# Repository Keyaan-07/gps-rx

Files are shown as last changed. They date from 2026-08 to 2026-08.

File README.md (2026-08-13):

# GPS Receiver
GPS-RX is a custom-hardware, low-power GPS receiver that is just 16x16mm in size. This receiver does not have any COCOM limits and is fully customisable. It uses UART to communicate with other external controllers and takes a 3.3 volt input. Unlike other GPS receivers, there are no speed or height based limits and can go to any height or any speeds. It is built like a really small module and can be built and assembled by anyone and used basically everywhere. I built this project to learn verilog and also because this seems really cool! The ice40up5k from lattice semiconductor is the FPGA that processes the GPS signals. 

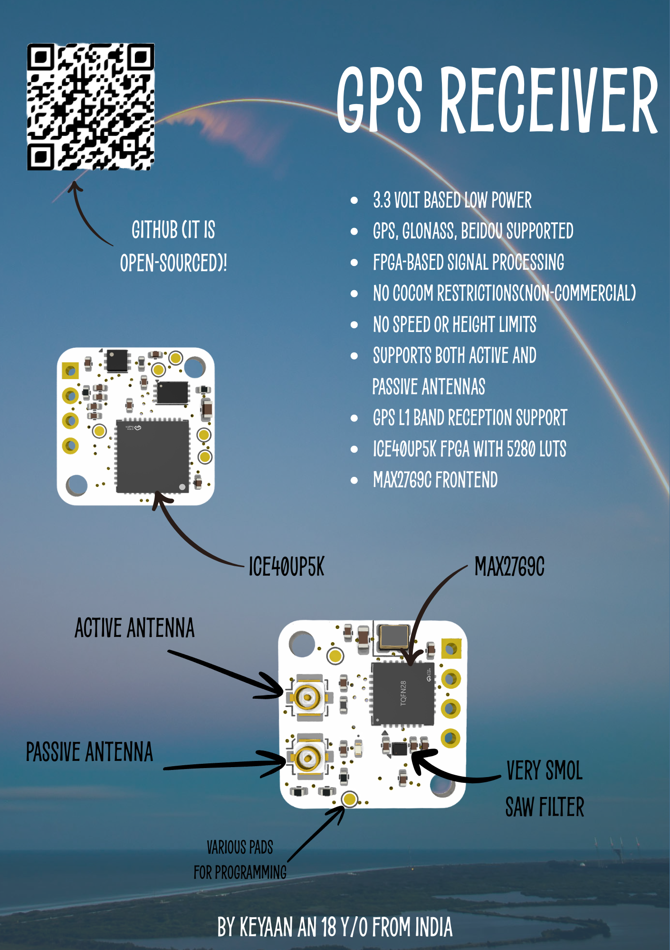
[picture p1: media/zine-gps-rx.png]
zine

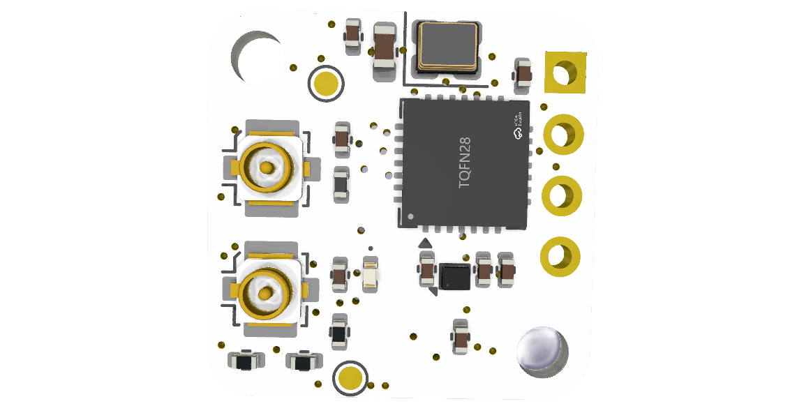
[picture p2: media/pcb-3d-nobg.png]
3d pcb

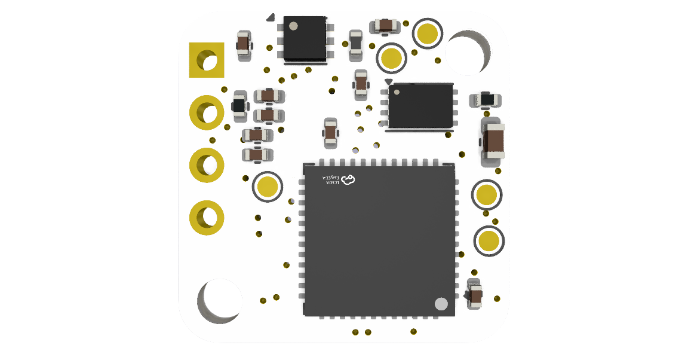
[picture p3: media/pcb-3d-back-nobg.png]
3d pcb back

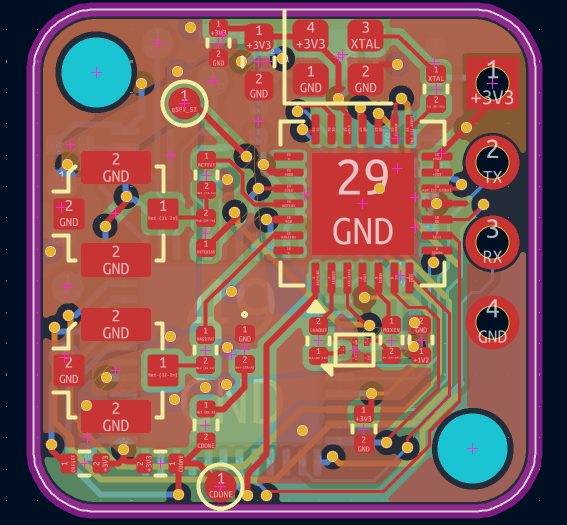
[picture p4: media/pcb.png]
pcb

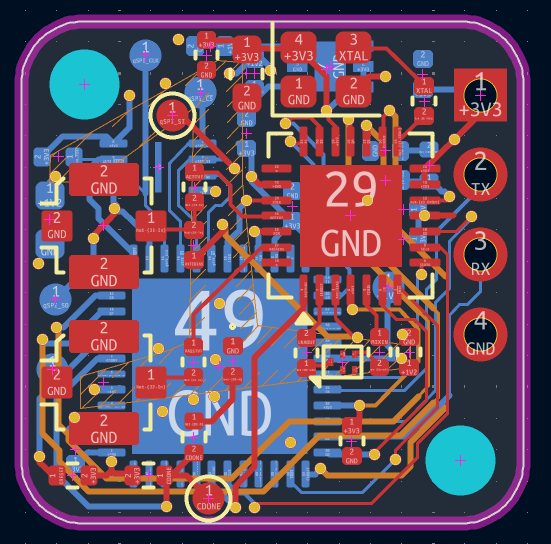
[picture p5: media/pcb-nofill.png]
pcb no fill

schematic

### Assembly instructions
1. Order the PCB from the gerber files in the [production](/hardware/production/) folder. Get two stencils(one for the top and one for the bottom).
2. Either get PCBA, or solder the components yourself. 
3. If soldering yourself, place the top side stencil over the top side and apply paste. Place all the components. 
4. Reflow the top side. 
5. Do the same process for the bottom side!
6. Program the firmware by connecting to the test points. 
7. Your receiver is ready!

### Note about firmware: GPS firmware development without the actual board will be really hard, thus i am not writing the firmware right now. 

## BOM
|Designator |Function |Value |Footprint |Quantity|Price |Amount|Link |
|---|---|---|---|---|---|---|---|
|PCB+stencil |PCB+stencil |Front and back both|16x16mm |5+2 |2.1+6.14 |8.24  |https://jlcpcb.com/ |
|C11, C9 |Capacitor |100p |402 |50 |0.0112 |0.56  |https://www.lcsc.com/product-detail/C77177.html |
|C12, C13, C14, C15, C18, C2, C4, C8|Capacitor |100n |402 |100 |0.0067 |0.67  |https://www.lcsc.com/product-detail/C60474.html |
|C19 |Capacitor |27p |402 |100 |0.0036 |0.36  |https://www.lcsc.com/product-detail/C1557.html |
|C20, C23, C24, C3, C5 |Capacitor |470p |402 |50 |0.0176 |0.88  |https://www.lcsc.com/product-detail/C76971.html |
|C21, C22 |Capacitor |10u |603 |10 |0.04 |0.4 |https://www.lcsc.com/product-detail/C18164635.html |
|C6 |Capacitor |10n |402 |100 |0.0041 |0.41  |https://www.lcsc.com/product-detail/C5137480.html |
|D1 |LED |LED |402 |20 |0.0357 |0.714 |https://www.lcsc.com/product-detail/C5123495.html |
|FL1 |Filter |SAFFB1G56KB0F0A |Filter_1109-5_1.1x0.9mm |10 |0.072 |0.72  |https://www.lcsc.com/product-detail/C91647.html |
|J1, J2 |Connector |Conn_Coaxial_Small |U.FL_Molex_MCRF_73412-0110_Vertical |5 |0.1019 |0.51  |https://www.lcsc.com/product-detail/C88374.html |
|J3 |Connector |Conn_01x04_Pin |PinHeader_1x04_P2.54mm_Vertical |20 |0.026 |0.52  |https://www.lcsc.com/product-detail/C2691448.html |
|L1 |Inductor |27n |402 |10 |0.09 |0.9 |https://www.lcsc.com/product-detail/C882469.html |
|L2 |Inductor |2.2u |402 |5 |0.304 |1.52  |https://www.lcsc.com/product-detail/C3911260.html |
|R1, R2, R6 |Resistor |10k |402 |100 |0.0025 |0.25  |https://www.lcsc.com/product-detail/C2906861.html |
|R3 |Resistor |1k |402 |100 |0.0041 |0.41  |https://www.lcsc.com/product-detail/C106235.html |
|R4 |Resistor |20k |402 |100 |0.005 |0.5 |https://www.lcsc.com/product-detail/C93942.html |
|U2 |FPGA |ICE40UP5K-SG48I |QFN-48-1EP_7x7mm_P0.5mm_EP5.6x5.6mm |1 |8.56 |8.56  |https://www.lcsc.com/product-detail/C2678152.html |
|U3 |GPS Frontend |MAX2769C |TQFN-28-1EP_5x5mm_P0.5mm_EP3.25x3.25mm |1 |3.24 |3.24  |https://www.lcsc.com/product-detail/C400150.html |
|U4 |Buck |PAM2305CGF120 |DFN-6-1EP_2x2mm_P0.65mm_EP1x1.6mm |5 |0.198 |0.99  |https://www.lcsc.com/product-detail/C110511.html |
|U5 |qSPI storage |W25Q16JVUXIQ |Winbond_USON-8-1EP_3x2mm_P0.5mm_EP0.2x1.6mm|1 |1.62 |1.62  |https://www.lcsc.com/product-detail/C2843335.html |
|Y1 |TXCO Crystal 16.368MHz |1XXB16368MBA |Crystal_SMD_2520-4Pin_2.5x2.0mm |1 |0.95 |0.95  |https://www.lcsc.com/product-detail/C213423.html |
|Hot air gun |For soldering dual sided PCB| | |1 |45.18 |45.18 |https://robu.in/product/yihua-959d-ii-hot-air-gun-with-easy-nozzle-plug-pull-storage-stand-desoldering-smd-rework-soldering-station/|
| | | | | |Subtotal |69.864| |
| | | | | |JLC Shipping |13 | |
| | | | | |LCSC Shipping|9.26  | |
| | | | | |Total |92.124| |

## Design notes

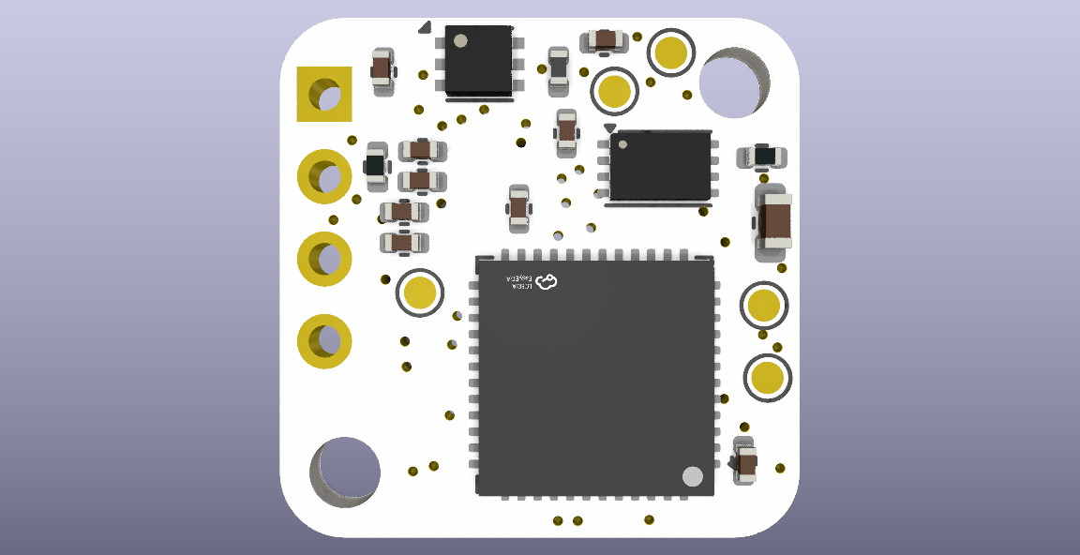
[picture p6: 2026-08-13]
media/pcb-3d-back.png

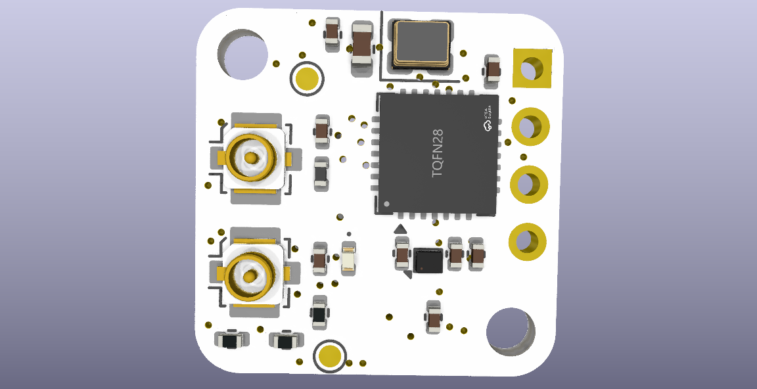
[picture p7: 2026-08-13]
media/pcb-3d.png

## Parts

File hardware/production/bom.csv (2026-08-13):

Designator | Footprint | Quantity | Value | LCSC Part #
C11, C9 | 0402 | 2 | 100p
C12, C13, C14, C15, C18, C2, C4, C8 | 0402 | 8 | 100n
C19 | 0402 | 1 | 27p
C20, C23, C24, C3, C5 | 0402 | 5 | 470p
C21, C22 | 0603 | 2 | 10u
C6 | 0402 | 1 | 10n
D1 | 0402 | 1 | LED
FL1 | Filter_1109-5_1.1x0.9mm | 1 | SAFFB1G56KB0F0A
J1, J2 | U.FL_Molex_MCRF_73412-0110_Vertical | 2 | Conn_Coaxial_Small
J3 | PinHeader_1x04_P2.54mm_Vertical | 1 | Conn_01x04_Pin
L1 | 0402 | 1 | 27n
L2 | 0402 | 1 | 2.2u
R1, R2, R6 | 0402 | 3 | 10k
R3 | 0402 | 1 | 1k
R4 | 0402 | 1 | 20k
TP10, TP2, TP3, TP4, TP5, TP6, TP7 | TestPoint_Pad_D1.0mm | 7 | TestPoint
U2 | QFN-48-1EP_7x7mm_P0.5mm_EP5.6x5.6mm | 1 | ICE40UP5K-SG48I
U3 | TQFN-28-1EP_5x5mm_P0.5mm_EP3.25x3.25mm | 1 | MAX2769C
U4 | DFN-6-1EP_2x2mm_P0.65mm_EP1x1.6mm | 1 | PAM2305CGF120
U5 | Winbond_USON-8-1EP_3x2mm_P0.5mm_EP0.2x1.6mm | 1 | W25Q16JVUXIQ
Y1 | Crystal_SMD_2520-4Pin_2.5x2.0mm | 1 | 1XXB16368MBA

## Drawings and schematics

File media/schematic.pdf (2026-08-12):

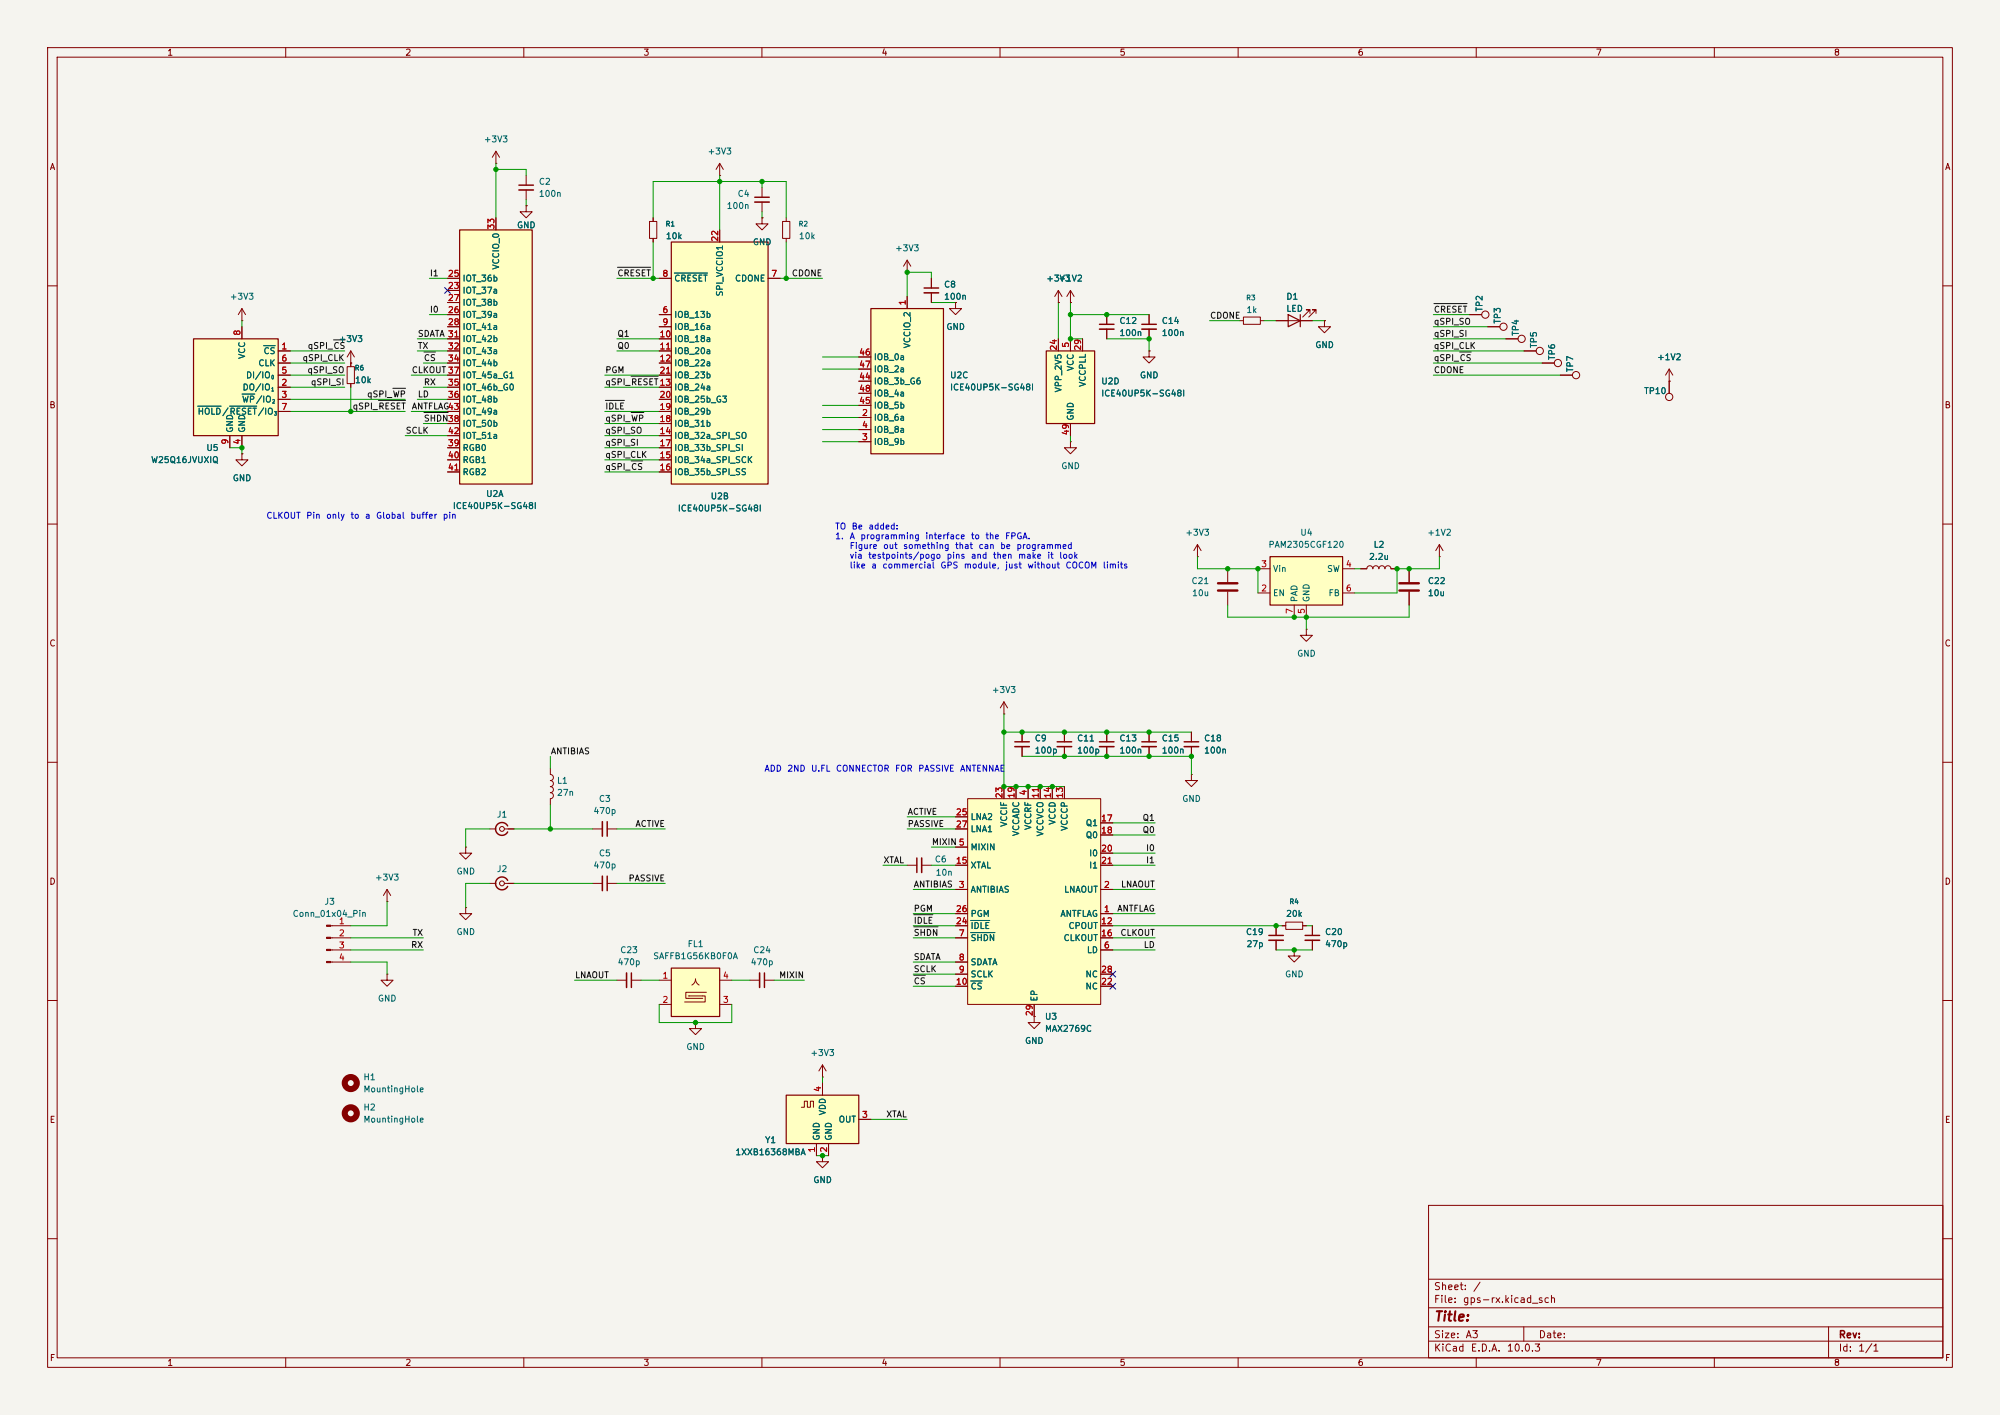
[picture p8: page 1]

like a commercial GPS module, just without COCOM limits GND U2B

4 DI/IO0 5 CLK 6 HOLD/RESET/IO3 7 VCC

qSPI_SI CLKOUT Pin only to a Global buffer pin

TO Be added: 1. A programming interface to the FPGA. Figure out something that can be programmed

via testpoints/pogo pins and then make it look

ADD 2ND U.FL CONNECTOR FOR PASSIVE ANTENNAE

Size: A3 | Rev: | F Date:
KiCad E.D.A. 10.0.3 | Id: 1/1

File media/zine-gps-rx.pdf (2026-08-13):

# GPSRECEIVER

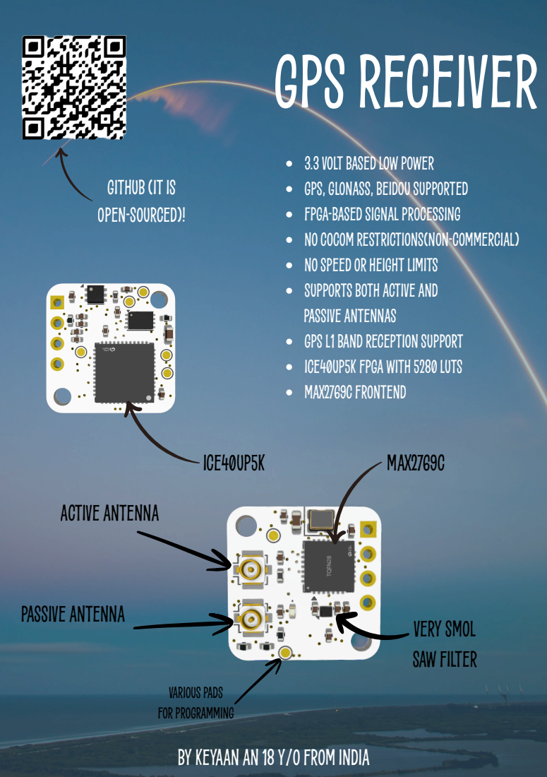
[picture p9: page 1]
3.3VOLTBASEDLOW POWER GPS,GLONASS,BEIDOUSUPPORTED FPGA-BASEDSIGNALPROCESSING NOCOCOM RESTRICTIONS(NON-COMMERCIAL) NOSPEEDORHEIGHTLIMITS SUPPORTSBOTHACTIVEAND PASSIVEANTENNAS GPSL1BANDRECEPTIONSUPPORT ICE40UP5KFPGA WITH5280LUTS MAX2769CFRONTEND; GITHUB(ITIS OPEN-SOURCED)!; ACTIVEANTENNA; PASSIVEANTENNA; BYKEYAANAN18Y/OFROM INDIA; MAX2769C; VERYSMOL SAW FILTER; ICE40UP5K; VARIOUSPADS FORPROGRAMMING

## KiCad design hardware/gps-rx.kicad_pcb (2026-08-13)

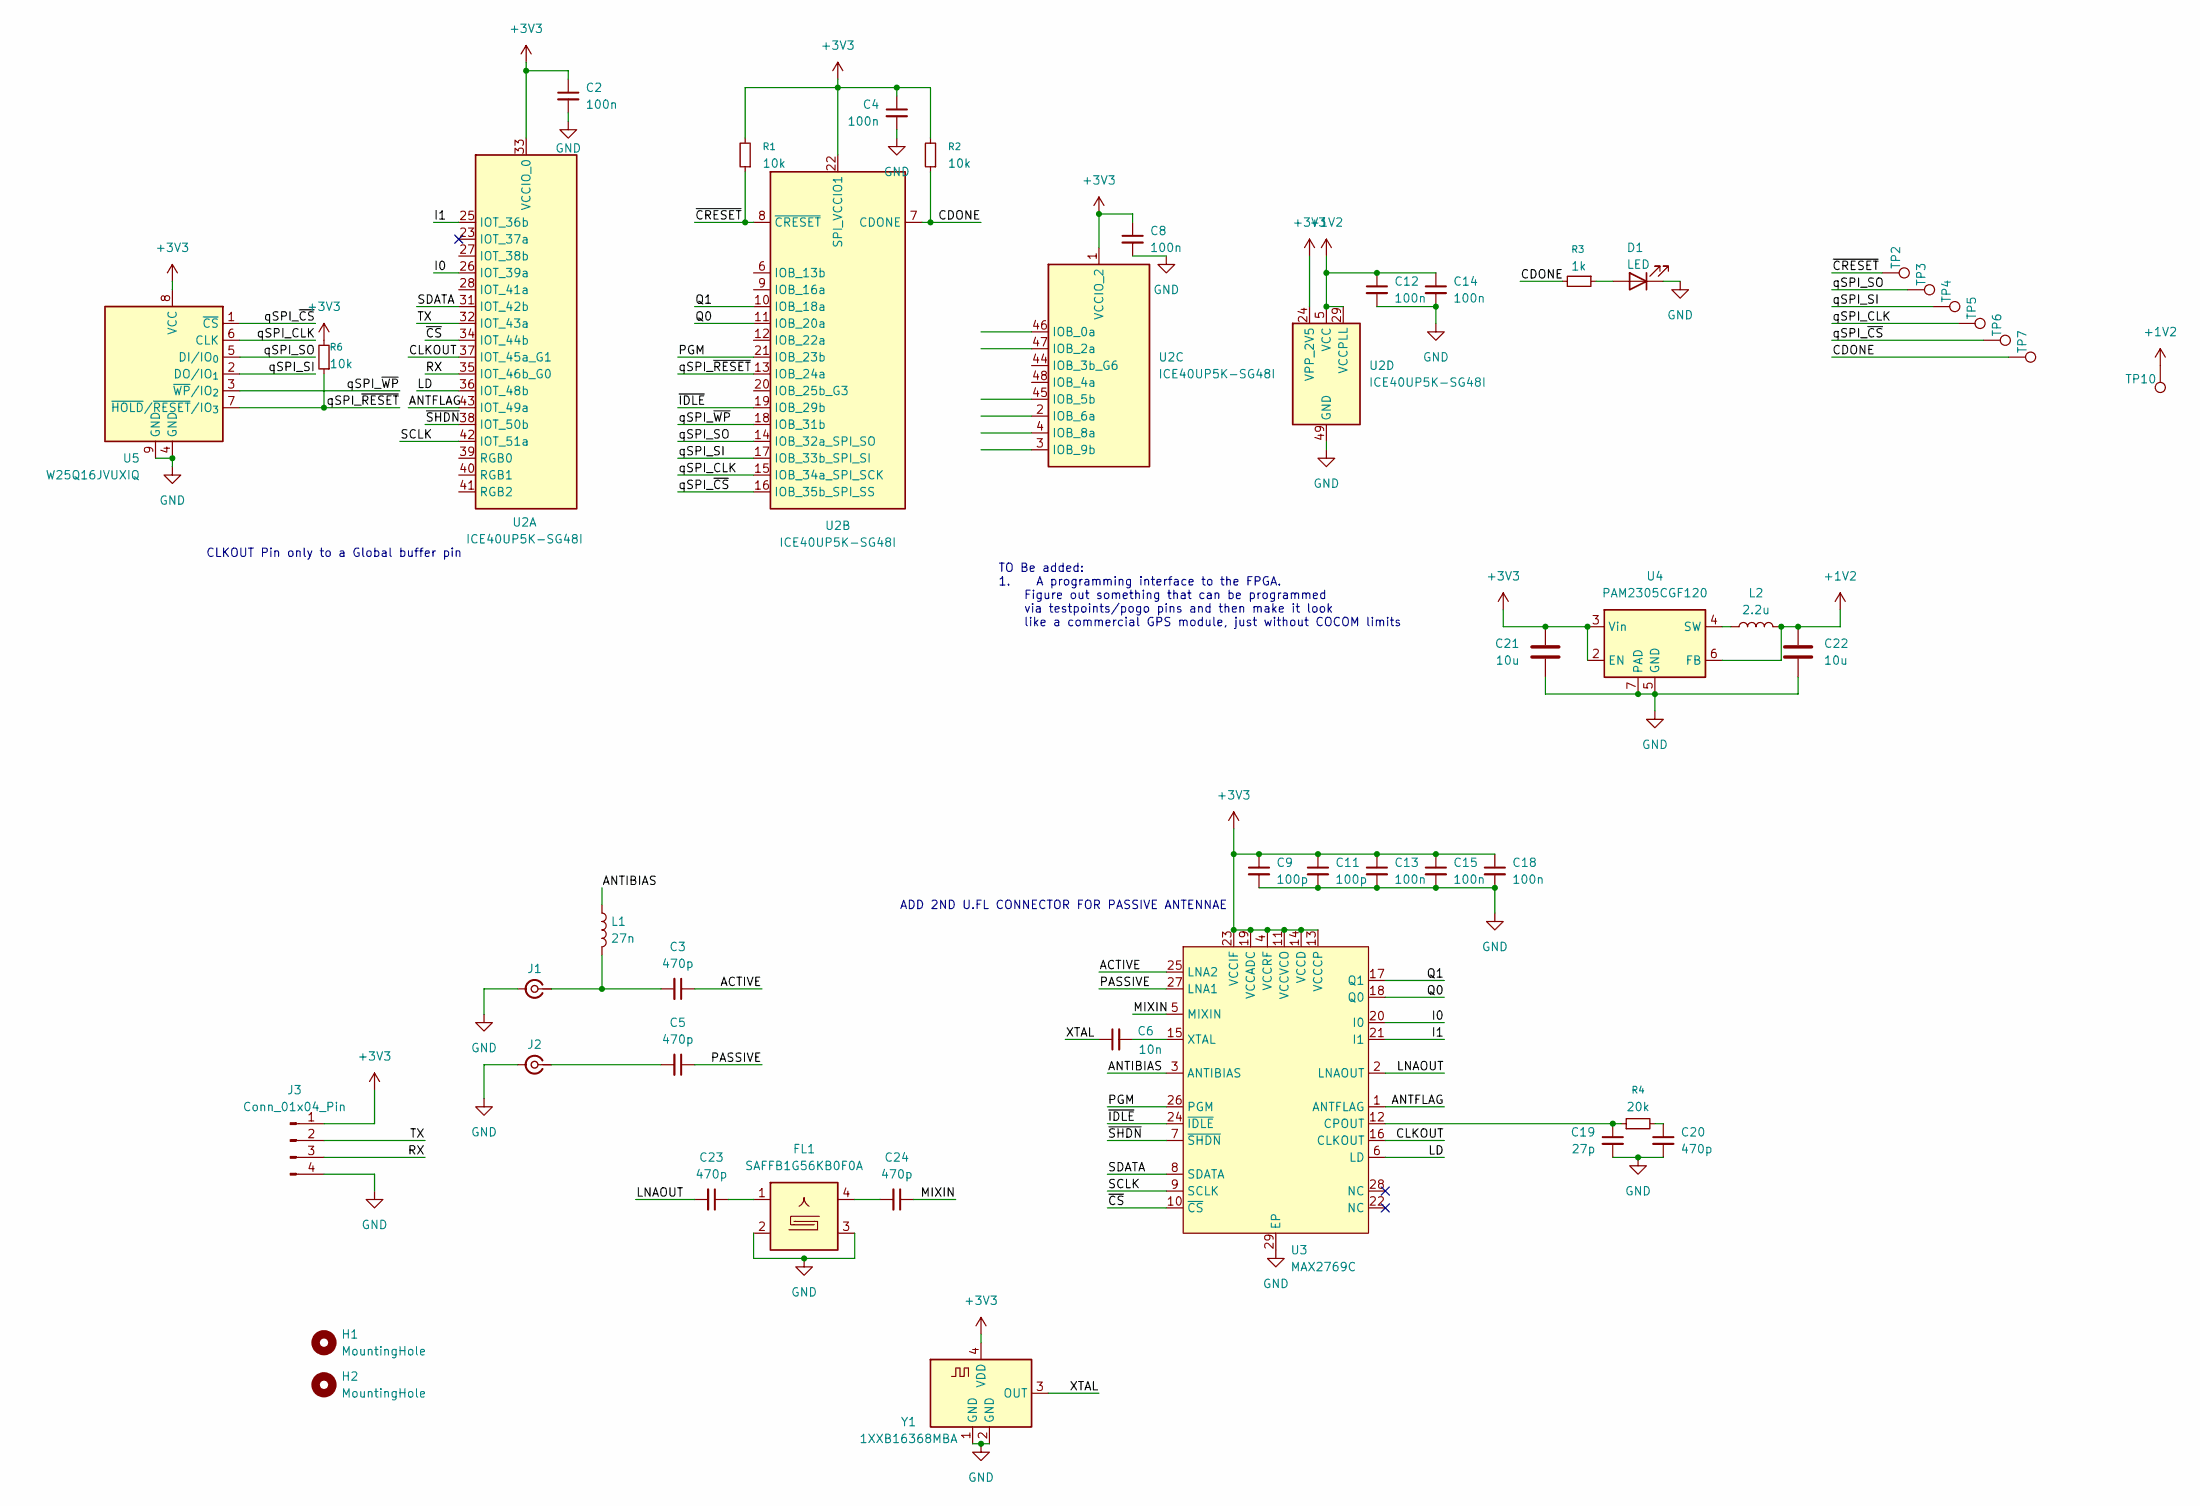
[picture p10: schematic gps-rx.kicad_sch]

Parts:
C2, C4, C8, C12, C13, C14, C15, C18: 100n; C_0402_1005Metric
C3, C5, C20, C23, C24: 470p; C_0402_1005Metric
C6: 10n; C_0402_1005Metric
C9, C11: 100p; C_0402_1005Metric
C19: 27p; C_0402_1005Metric
C21, C22: 10u; C_0603_1608Metric
D1: LED; LED_0402_1005Metric
FL1: SAFFB1G56KB0F0A; Filter_1109-5_1.1x0.9mm
H1, H2: MountingHole; MountingHole_2.2mm_M2
J1, J2: Conn_Coaxial_Small; U.FL_Molex_MCRF_73412-0110_Vertical
J3: Conn_01x04_Pin; PinHeader_1x04_P2.54mm_Vertical
L1: 27n; L_0402_1005Metric
L2: 2.2u; L_0402_1005Metric
R1, R2, R6: 10k; R_0402_1005Metric
R3: 1k; R_0402_1005Metric
R4: 20k; R_0402_1005Metric
TP2, TP3, TP4, TP5, TP6, TP7, TP10: TestPoint; TestPoint_Pad_D1.0mm
U2: ICE40UP5K-SG48I; QFN-48-1EP_7x7mm_P0.5mm_EP5.6x5.6mm
U3: MAX2769C; TQFN-28-1EP_5x5mm_P0.5mm_EP3.25x3.25mm
U4: PAM2305CGF120; DFN-6-1EP_2x2mm_P0.65mm_EP1x1.6mm
U5: W25Q16JVUXIQ; Winbond_USON-8-1EP_3x2mm_P0.5mm_EP0.2x1.6mm
Y1: 1XXB16368MBA; Crystal_SMD_2520-4Pin_2.5x2.0mm

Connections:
+1V2: C12.1, C14.1, C22.1, L2.2, TP10.1 (1_1), U2.5 (VCC), U2.29 (VCCPLL), U2.30 (VCC), U4.6 (FB)
+3V3: C2.1, C4.1, C8.1, C9.1, C11.1, C13.1, C15.1, C18.1, C21.1, J3.1, R1.2, R2.2, R6.2, U2.1 (VCCIO_2), U2.22 (SPI_VCCIO1), U2.24 (VPP_2V5), U2.33 (VCCIO_0), U3.4 (VCCRF), U3.11 (VCCVCO), U3.13 (VCCCP), U3.14 (VCCD), U3.19 (VCCADC), U3.23 (VCCIF), U4.2 (EN), U4.3 (Vin), U5.8 (VCC), Y1.4 (VDD)
/ACTIVE: C3.1, U3.25 (LNA2)
/ANTFLAG: U2.43 (IOT_49a), U3.1 (ANTFLAG)
/ANTIBIAS: L1.1, U3.3 (ANTIBIAS)
/CDONE: R2.1, R3.2, TP7.1 (1_1), U2.7 (CDONE)
/CLKOUT: U2.37 (IOT_45a_G1), U3.16 (CLKOUT)
/I0: U2.26 (IOT_39a), U3.20 (I0)
/I1: U2.25 (IOT_36b), U3.21 (I1)
/LD: U2.36 (IOT_48b), U3.6 (LD)
/LNAOUT: C23.2, U3.2 (LNAOUT)
/MIXIN: C24.1, U3.5 (MIXIN)
/PASSIVE: C5.1, U3.27 (LNA1)
/PGM: U2.21 (IOB_23b), U3.26 (PGM)
/Q0: U2.11 (IOB_20a), U3.18 (Q0)
/Q1: U2.10 (IOB_18a), U3.17 (Q1)
/RX: J3.3, U2.35 (IOT_46b_G0)
/SCLK: U2.42 (IOT_51a), U3.9 (SCLK)
/SDATA: U2.31 (IOT_42b), U3.8 (SDATA)
/TX: J3.2, U2.32 (IOT_43a)
/XTAL: C6.1, Y1.3 (OUT)
/qSPI_CLK: TP5.1 (1_1), U2.15 (IOB_34a_SPI_SCK), U5.6 (CLK)
/qSPI_SI: TP4.1 (1_1), U2.17 (IOB_33b_SPI_SI), U5.2 (DO/IO_{1})
/qSPI_SO: TP3.1 (1_1), U2.14 (IOB_32a_SPI_SO), U5.5 (DI/IO_{0})
/qSPI_~CS: TP6.1 (1_1), U2.16 (IOB_35b_SPI_SS), U5.1 (~CS)
/qSPI_~RESET: R6.1, U2.13 (IOB_24a), U5.7 (~HOLD/~RESET/IO_{3})
/qSPI_~WP: U2.18 (IOB_31b), U5.3 (~WP/IO_{2})
/~CRESET: R1.1, TP2.1 (1_1), U2.8 (~CRESET)
/~CS: U2.34 (IOT_44b), U3.10 (~CS)
/~IDLE: U2.19 (IOB_29b), U3.24 (~IDLE)
/~SHDN: U2.38 (IOT_50b), U3.7 (~SHDN)
GND: C2.2, C4.2, C8.2, C9.2, C11.2, C12.2, C13.2, C14.2, C15.2, C18.2, C19.2, C20.2, C21.2, C22.2, D1.1 (K), FL1.2, FL1.3, FL1.5, J1.2 (Ext), J2.2 (Ext), J3.4, U2.49 (GND), U3.29 (EP), U4.5 (GND), U4.7 (PAD), U5.4 (GND), U5.9 (GND), Y1.1 (GND), Y1.2 (GND)
unnamed: C20.1, R4.2
unnamed: C23.1, FL1.1
unnamed: C24.2, FL1.4
unnamed: D1.2 (A), R3.1
unnamed: C3.2, J1.1 (In), L1.2
unnamed: C5.2, J2.1 (In)
unnamed: C19.1, R4.1, U3.12 (CPOUT)
unnamed: C6.2, U3.15 (XTAL)
unnamed: L2.1, U4.4 (SW)

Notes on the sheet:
CLKOUT Pin only to a Global buffer pin
ADD 2ND U.FL CONNECTOR FOR PASSIVE ANTENNAE
TO Be added: 1. A programming interface to the FPGA. Figure out something that can be programmed via testpoints/pogo pins and then make it look like a commercial GPS module, just without COCOM limits

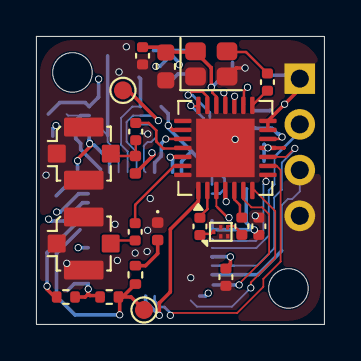
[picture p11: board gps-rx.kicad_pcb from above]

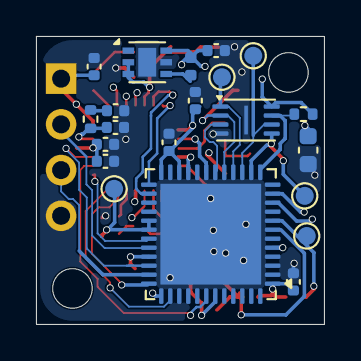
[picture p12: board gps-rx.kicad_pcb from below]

Board: 4 copper layers, 16.0 x 16.0 mm, 45 parts (22 on the bottom side), 41 nets.

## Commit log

2026-06-28 Hello World
    [gps-rx.kicad_pcb, gps-rx.kicad_sch]
2026-06-28 new project specific library
    [gps-rx.kicad_pcb, gps-rx.kicad_sch]
2026-07-18 new stuff
    [gps-rx.kicad_pcb, gps-rx.kicad_sch]
2026-07-30 new PCB design
    [gps-rx.kicad_pcb, gps-rx.kicad_sch]
2026-08-12 added images of PCB and schematic
2026-08-12 PCB completed
    [gps-rx.kicad_pcb, gps-rx.kicad_sch]
2026-08-12 PCB image
2026-08-13 production files
    [bom.csv, designators.csv, gps-rx.kicad_pcb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]
2026-08-13 added bom
    [bom.csv]
